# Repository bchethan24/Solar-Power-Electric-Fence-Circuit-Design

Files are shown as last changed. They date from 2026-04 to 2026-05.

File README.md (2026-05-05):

# Solar Powered Electric Fence Circuit

*A high-voltage, renewable energy-based perimeter security system using CD4047 pulse generation and MOSFET power switching.*

---

## Overview

This project features a fully custom-built **Solar Powered Electric Fence**, designed to deliver controlled, safe high-voltage pulses for agricultural and perimeter protection. It integrates a solar charging system with a battery backup to ensure 24/7 off-grid operation without reliance on the power grid.

---

## System Architecture
```
┌────────────────────────────┐       ┌────────────────────────────┐
│   Solar Charging Stage     │       │   Pulse Generation Stage   │
│ • 12V Solar Panel          │       │ • CD4047 Multivibrator     │
│ • LM317L Voltage Regulator │◄─────►│ • Adjustable Frequency     │
│ • 12V 7Ah Battery Storage  │       │ • 46 Hz – 58 Hz Range      │
└────────────────────────────┘       └─────────────┬──────────────┘
                                                   │
                                                   ▼
┌────────────────────────────┐       ┌────────────────────────────┐
│   High-Voltage Stage       │       │      Switching Stage       │
│ • Step-up Transformer      │◄─────►│ • Dual IRF3205 MOSFETs     │
│ • High-Voltage Pulse Out   │       │ • High-Current Handling    │
│ • Safe Deterrent Shocks    │       │ • Low-Loss Power Switching │
└────────────────────────────┘       └────────────────────────────┘
```

## ⚙ Working Principle

1. **Energy Harvesting:** The solar panel generates DC power, which is regulated by the **LM317L** to provide a constant charging voltage to the **12V 7Ah Lead-Acid battery**.
2. **Pulse Timing:** A **CD4047 IC** is configured in astable mode to produce a continuous square wave. The frequency is adjustable (**46–58 Hz**) via a variable resistor to fine-tune the deterrent intensity.
3. **Power Switching:** The logic-level signal from the IC drives the gates of two **IRF3205 MOSFETs**. These MOSFETs switch the battery current through the primary winding of the transformer.
4. **Inductive Boost:** The **Step-up Transformer** converts the low-voltage switched DC into high-voltage, short-duration pulses suitable for long-distance fencing wires.

---

## 🧩 Detailed Hardware Information

### 🧮 Pulse Generation (CD4047)
The timing is governed by the RC network connected to the astable multivibrator pins.

| Component | Value | Function |
| :--- | :--- | :--- |
| **Resistor (R)** | 390 kΩ + 100 kΩ Pot | Frequency Tuning |
| **Capacitor (C)** | 10 nF | Timing Constant |
| **Pulse Period (T)** | 17.16 – 21.56 ms | T = 4.4RC |
| **Frequency (f)** | 46 Hz – 58 Hz | Output Pulse Rate |

### 🔋 Power & Switching
| Component | Specification | Role |
| :--- | :--- | :--- |
| **Voltage Regulator** | LM317L | Battery Charge Control |
| **Storage** | 12V, 7Ah Battery | Lead-Acid Energy Storage |
| **Switching MOSFET** | IRF3205 | High-Current Driver ($V_{DSS}=55V$) |
| **Protection** | Schottky Diodes | Reverse Polarity & Surge Protection |

---

## 📐 Design Features

* **Fully Custom Design:** Optimized schematics and PCB layouts specifically for high-current pulse switching.
* **Off-Grid Optimized:** Designed for outdoor operation with minimal maintenance.
* **Safety Integrated:** Intermittent pulse generation ensures shocks are deterrent but safe for livestock and humans.
* **Modular Layout:** Segmented circuit stages for charging, control, and high-voltage output for easier troubleshooting.

---

## 📂 Repository Contents
- `/hardware`: Schematics, PCB layouts and 3D PCB layout visualizations.
- `/docs`: component datasheets and project report.
- `/manufacturing`: Gerber files of the PCB layouts.

---

## 🧠 Learning Outcomes
- Designing **Battery Charging Circuits** with voltage regulation.
- Implementing **Astable Multivibrators** for precise signal timing.
- Managing **High-Voltage switching** 
- Integrating **Renewable Energy** into practical security applications.

---

## 🧾 License
**MIT License** Permission is granted to use, modify, and distribute under MIT terms.

---

## ✅ Summary
A robust, solar-powered security solution that demonstrates the practical application of **Power Electronics** and **Analog Design**. The system provides a sustainable, cost-effective deterrent for livestock and perimeter management, verified through rigorous testing and custom PCB fabrication.

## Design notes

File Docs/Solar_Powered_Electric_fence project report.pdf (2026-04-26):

P a g e 1 | 18

## Indian Institute of Information Technology Design and Manufacturing, Kurnool

Department of Electronics and Communication Engineering Bachelor of Technology

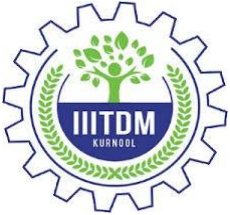
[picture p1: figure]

## Project Report

# Solar Powered Electric Fence

Team members

Praneesh | - 123EC0043
Chethan | - 123EC0049
Abhilash | - 123EC0053
Manideep - 523EC0004
Dinesh - 523EC0007

P a g e 2 | 18

# INDEX

P a g e 3 | 18

### 1. About the Project

### 1.1 Project Aim

The Solar Electric Fence project aims to develop a low-cost, efficient, and renewable energy-powered fencing system. This system is designed to protect agricultural crops and livestock by delivering controlled electric pulses along a fence line. Unlike traditional fencing systems which require mains power or manual management, the solar electric fence harnesses solar energy to operate off-grid, making it ideal for rural and remote locations.

### 1.2 Components and Their Roles

- Solar Panel: Converts sunlight into electrical energy (DC), which powers the entire system and charges the battery.
- Battery (12V 7Ah): Stores electrical energy generated by the solar panel to supply continuous power even during night time or low sunlight.
- LM317L Adjustable Voltage Regulator: Ensures the battery is charged safely with astable and adjustable voltage, protecting it from Voltage fluctuations.
- N-Channel HEXFET Power MOSFETs (IRF3205): Act as electronic switches that drive high-current pulses from the battery into the transformer, enabling efficient pulse generation.
- Transformer: Steps up the low voltage pulses from MOSFETs to high voltage pulses required for energizing the fence wire.
- CD4047 IC: Functions as a pulse generator (astable multi vibrator) to create timing signals that control the switching of the MOSFETs, thereby dictating the pulse repetition rate.

P a g e 4 | 18
- Schottky Diodes: Protect the circuit by preventing reverse current flow, especially during switching and charging phases, owing to their low forward voltage drop and fast switching capability.
- Resistors: Used throughout the circuit for current limiting, voltage division, setting timing parameters, and biasing components.
- Polar and Non-Polar Capacitors: Used for filtering power ripple, timing in multi vibrator circuits, energy storage, and reducing electrical noise.
- LED Indicators: Provide visual feedback on power status, charging state, and pulse generation, facilitating easy monitoring.
- Switches: Allow manual control to enable or disable charging and fence energization.

### 2. Project Schematics

### 2.1 Overview

The schematic is divided into three major sections:

- Power Supply and Charging Circuit: Includes the solar panel input, diode protection, LM317L voltage regulator, charging control switches, and battery storage.
- Pulse Generation Circuit: Built around the CD4047 astable multi vibrator IC which generates a square wave to control the gate of MOSFETs.
- Pulse Amplification and Transformer Section: MOSFETs switch the battery power through the transformer primary, stepping voltage up to deliver sharp pulses on the fence wire.

BOARD 1

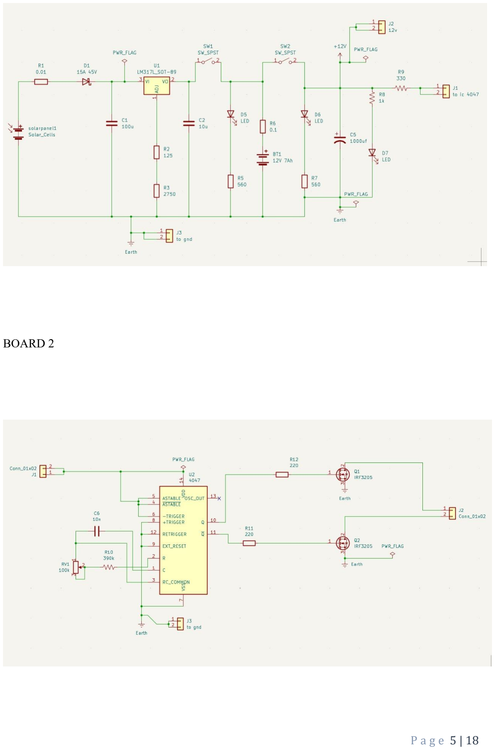
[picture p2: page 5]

P a g e 5 | 18

BOARD 2

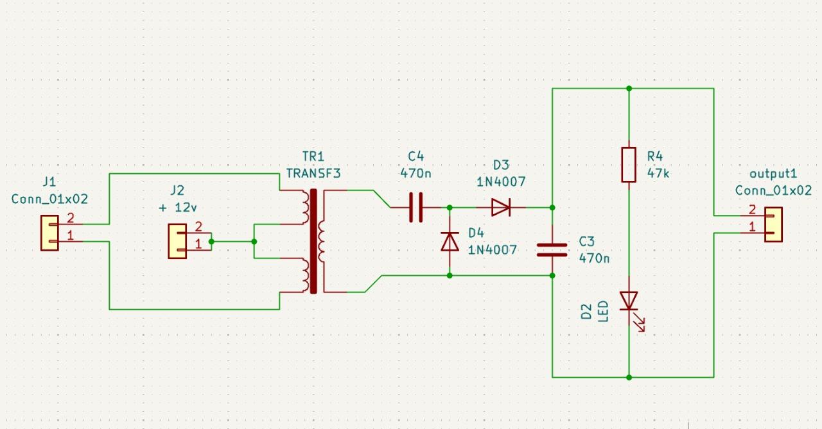
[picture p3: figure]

P a g e 6 | 18

BOARD 3

Figure : Schematic diagram of the Solar power Electric Fence

The schematic of the solar-powered electric fence circuit integrates all the essential power generation and pulse delivery stages, as summarized below:

- The solar panel interfaces with the battery charging circuit through diodes and capacitors to store energy, while switches and fuses regulate power input for safe operation.
- The 555 timer ICs provide pulse generation and triggering signals to drive the MOSFETs and transformer, enabling high-voltage output for fence energization.
- An ignition coil and transformer are used to step up the voltage from the 12V battery to deliver high-voltage pulses, ensuring effective deterrence along the fence wire.
- Supporting components such as resistors, capacitors, and LEDs are utilized for timing, filtering, status indication, and protection against electrical surges and faults.

P a g e 7 | 18

### 3. Working Principle

The core functioning of the solar electric fence depends on generating high-voltage electric pulses at regulated intervals:

1. The solar panel converts sunlight into DC electricity, charging the 12V battery through an LM317L voltage regulator to avoid overcharging.
2. The CD4047 IC is configured as an astable multi vibrator producing a continuous square wave used to switch MOSFETs alternately.
3. Each MOSFET switches the battery voltage through a center - tapped transformer primary winding, causing the transformer secondary to produce high-voltage pulses.
4. These pulses are transmitted along the fence wires. When an animal contacts the fence, the circuit completes briefly, delivering a safe but discomforting shock, thereby deterring intrusion.
5. LEDs and other indicators provide the user with system status, including battery charge and output pulse activity.

Pulse Timing Calculation

The pulse frequency, f, generated by the CD4047 in astable mode can be approximated by

where R and C are the timing resistor and capacitor connected externally to the IC. Adjusting these values changes the pulse repetition rate.

P a g e 8 | 18

### 4. Design Considerations

### 4.1 Electrical Considerations

Careful voltage and current regulation protects battery longevity. Efficient MOSFETs minimize power loss during switching. Use of Schottky diodes reduces voltage drop and improves circuit response times.

### 4.2 Layout and Wiring

Short, thick wires and neat PCB layout reduce resistance and interference. Proper placement of decoupling capacitors near active devices ensures stability.

### 4.3 Mechanical and Environmental

Components and wiring should be weatherproofed for outdoor use. Adequate spacing and mounting support thermal dissipation and protect parts against mechanical stress.

### 4.4 Thermal Management

High-current MOSFETs and voltage regulators should have heatsinks. Sufficient airflow and isolation prevent overheating and increase reliability.

### 5. Layout

The PCB layout has been designed for compactness, signal integrity, and ease of assembly. The layout optimizes routing of power and signal lines, placing critical components like the voltage regulator and MOSFETs to minimize noise and thermal hotspots.

BOARD 1

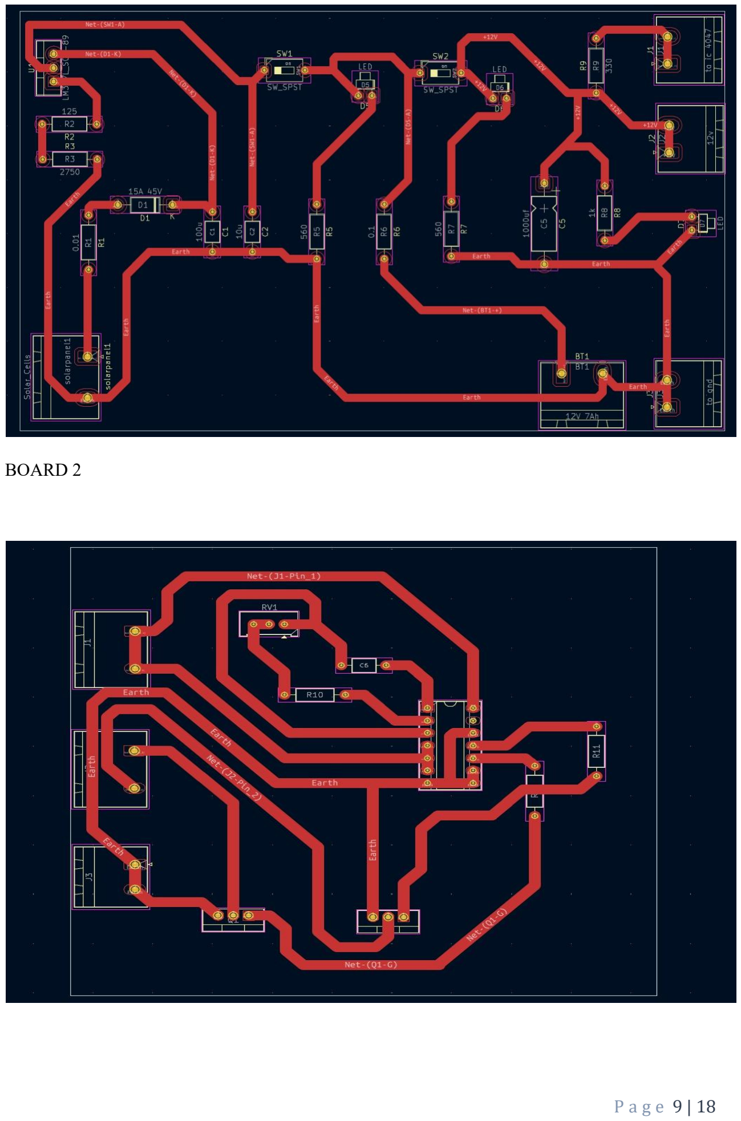
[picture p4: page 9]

P a g e 9 | 18

BOARD 2

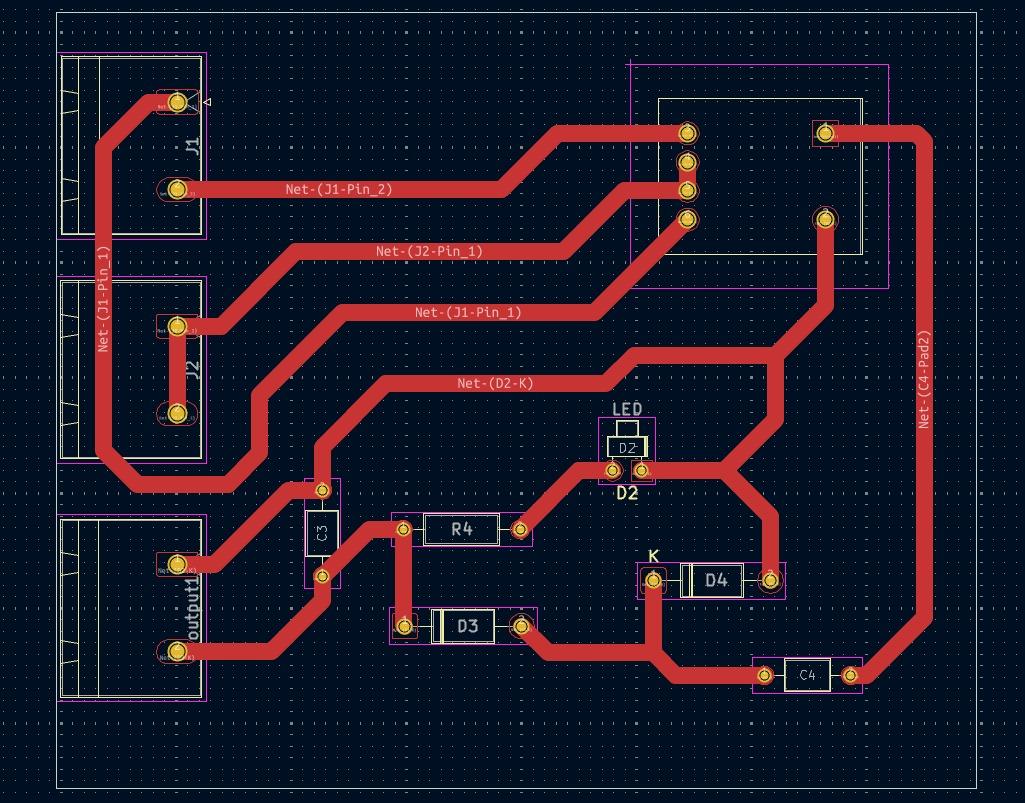
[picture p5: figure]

P a g e 10 | 18

BOARD 3

Figure 2: PCB layout

### 6. Front Copper

The front copper layer contains the main routing for power lines, signal traces, and pads for through-hole and surface mount components. Care was taken to ensure wide tracks for high current paths.

BOARD 1

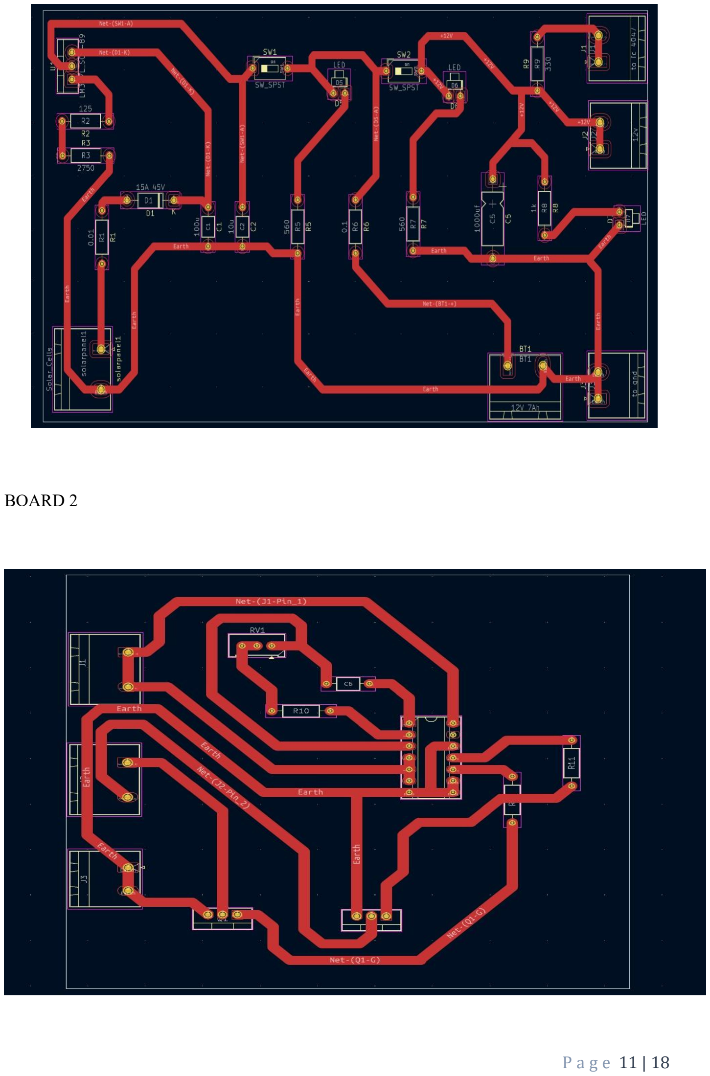
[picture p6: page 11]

P a g e 11 | 18

BOARD 2

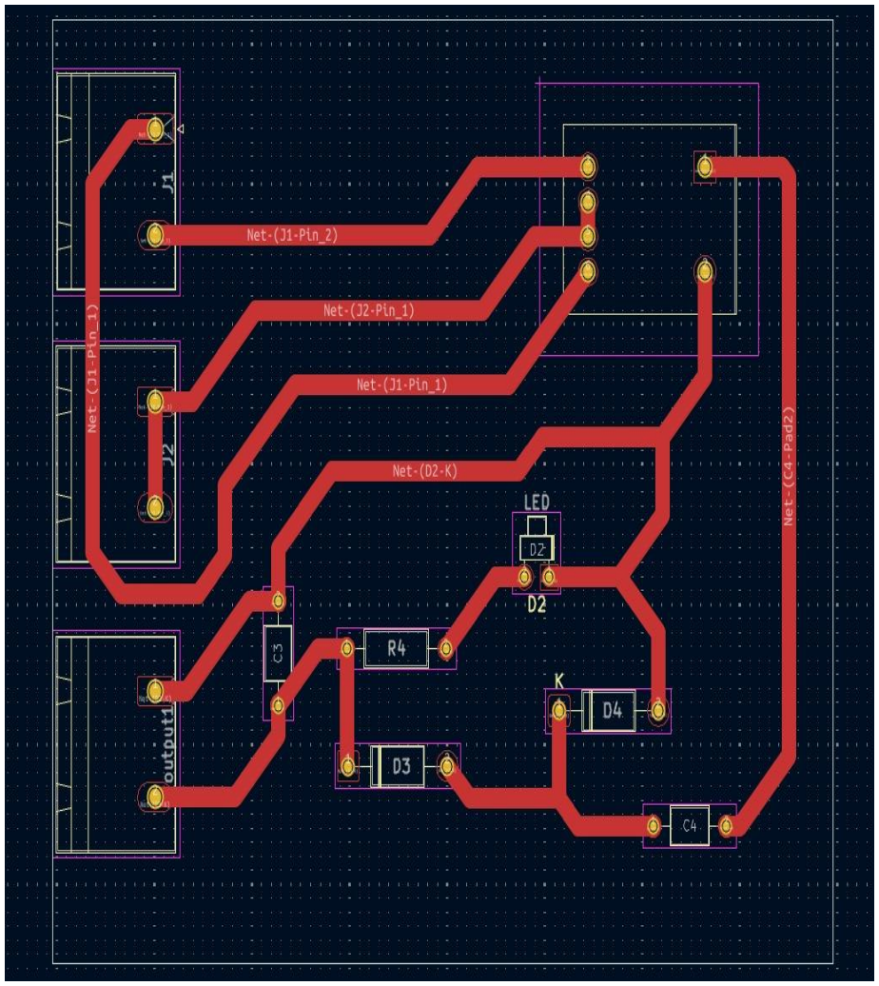
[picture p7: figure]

P a g e 12 | 18

BOARD 3

Figure: Front copper layer of the PCB.

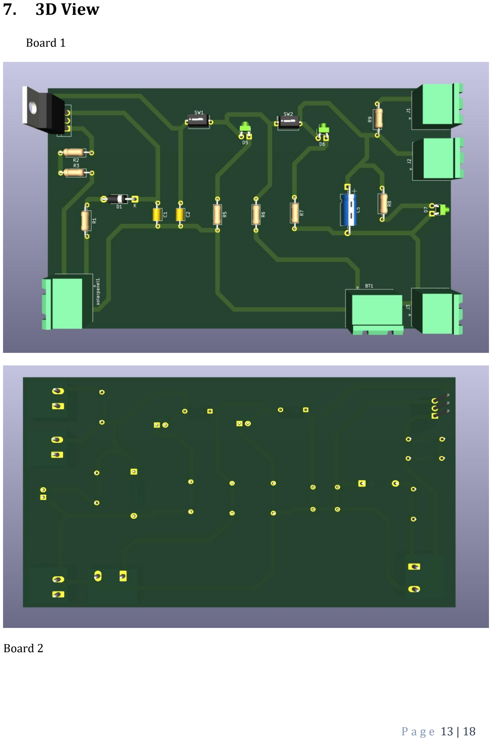
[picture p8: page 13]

P a g e 13 | 18

### 7. 3D View

Board 1

Board 2

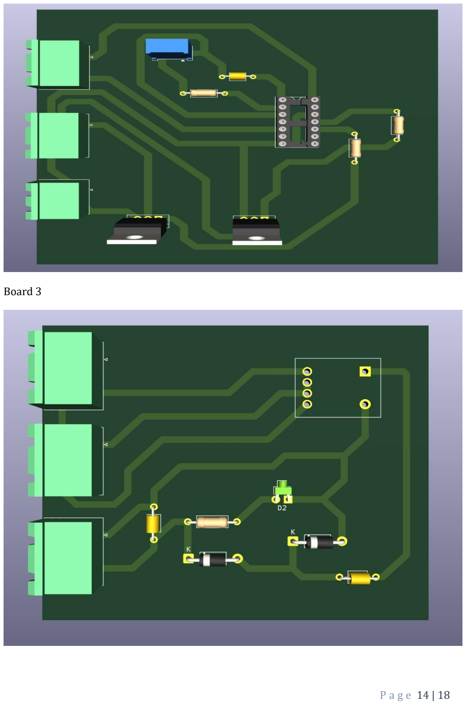
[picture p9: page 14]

P a g e 14 | 18

Board 3

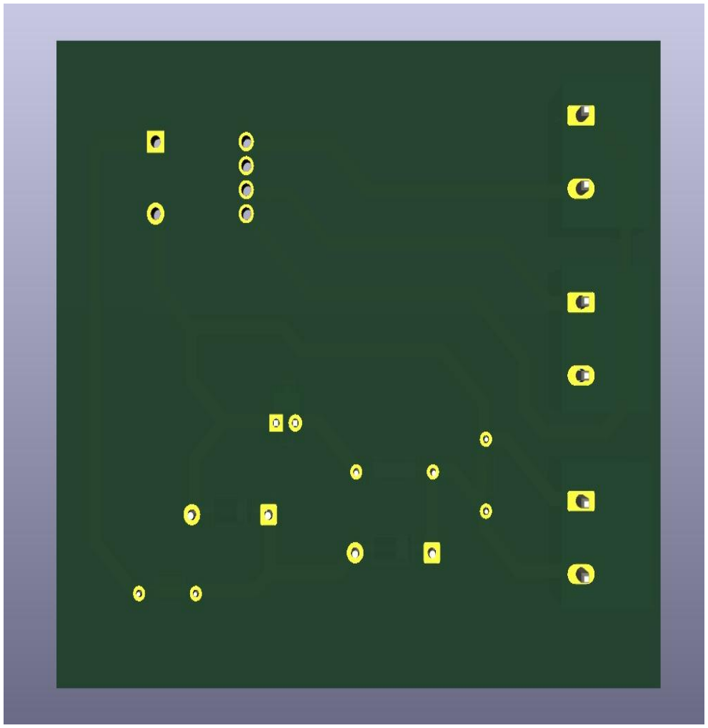
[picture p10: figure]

P a g e 15 | 18

### 8. Legends

The silkscreen legends provide the component designators, polarity indicators, and assembly guides for accurate component placement and troubleshooting.

BOARD 1

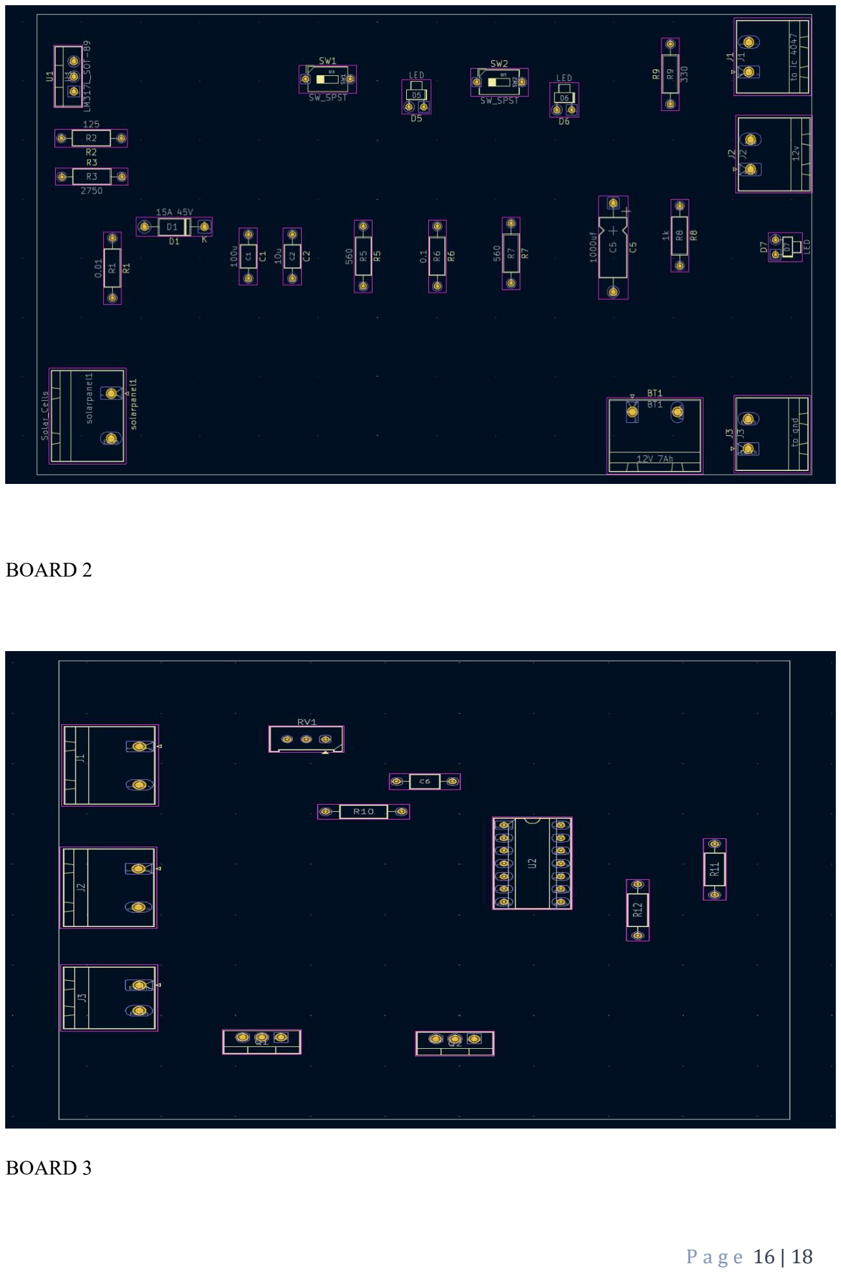
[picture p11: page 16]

P a g e 16 | 18

BOARD 2

BOARD 3

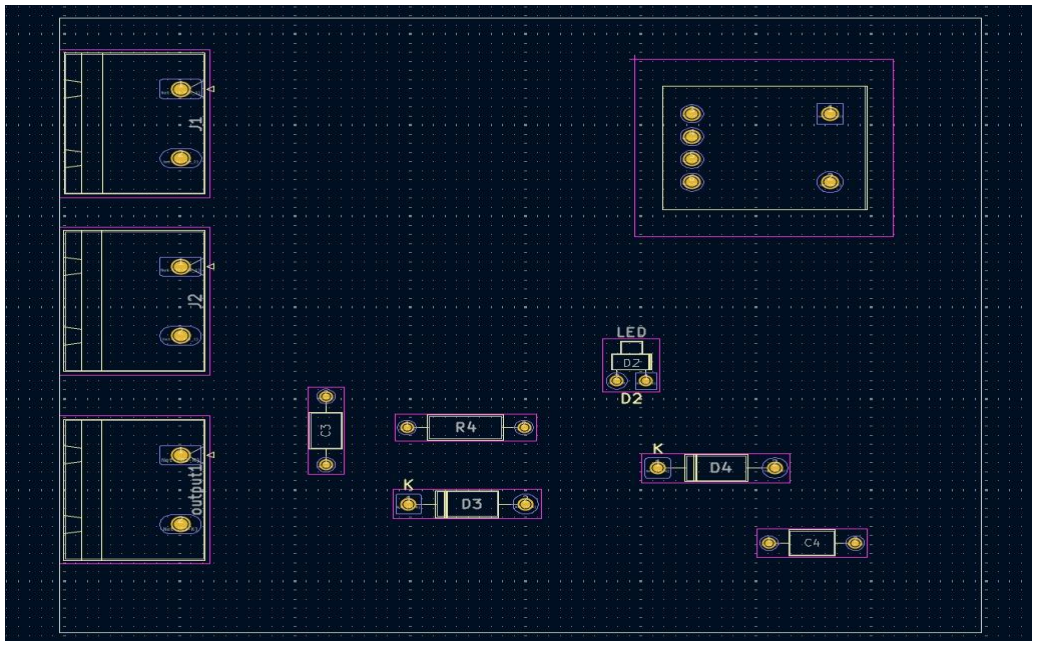
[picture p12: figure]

P a g e 17 | 18

Figures: Silkscreen Legend Layer of PCB

### 9. Overall Project Summary

The Solar Powered Electric Fence project demonstrates a sustainable and cost-effective solution for protecting agricultural fields and livestock using renewable energy. The system utilizes solar energy to power a fence that delivers controlled electric pulses, effectively deterring animals and intruders without causing harm.

The design integrates key electronic components such as the solar panel, LM317L voltage regulator, CD4047 IC, MOSFETs, transformer, and protective diodes to ensure reliable performance. The solar panel charges a 12V battery, enabling continuous operation even during night time or cloudy conditions. The CD4047 IC generates pulses that switch the MOSFETs, which in turn drive the transformer to produce high-voltage pulses transmitted along the fence wire.

P a g e 18 | 18

This project emphasizes energy efficiency, safety, and practicality. By operating completely off-grid, it offers a dependable fencing solution for remote and rural areas. The system’s PCB layout, thermal management, and protective design ensure durability and ease of maintenance in outdoor environments.

Overall, the project successfully integrates renewable energy, electronics, and safety engineering principles to create an effective solar-powered electric fencing system. It serves as a valuable step toward sustainable agricultural protection and energy-efficient rural technology.

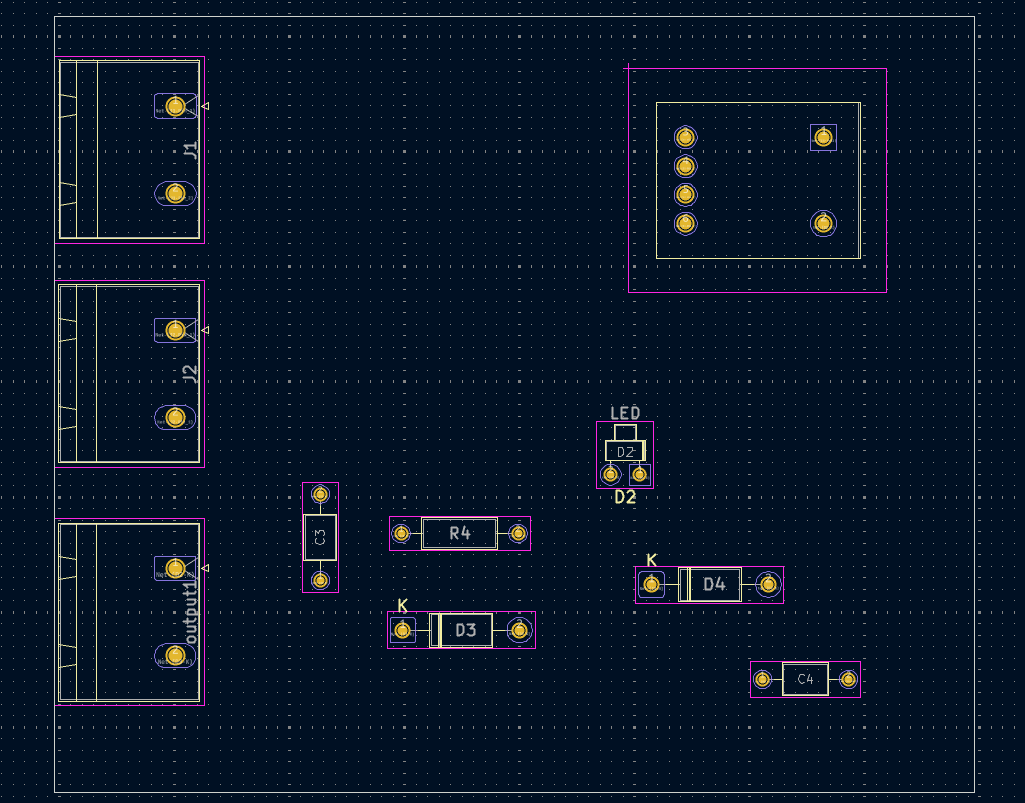
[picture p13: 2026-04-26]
Hardware/Main_Control_Board/Assets/third_part/legend.png

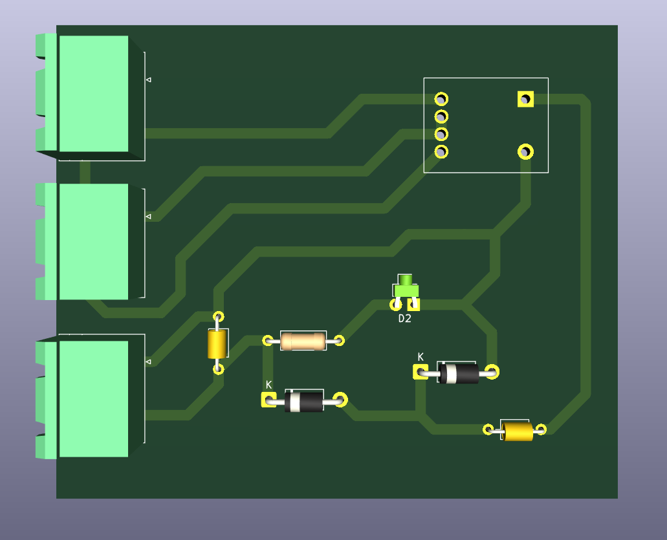
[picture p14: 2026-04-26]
Hardware/Main_Control_Board/Assets/third_part/3d front view.png

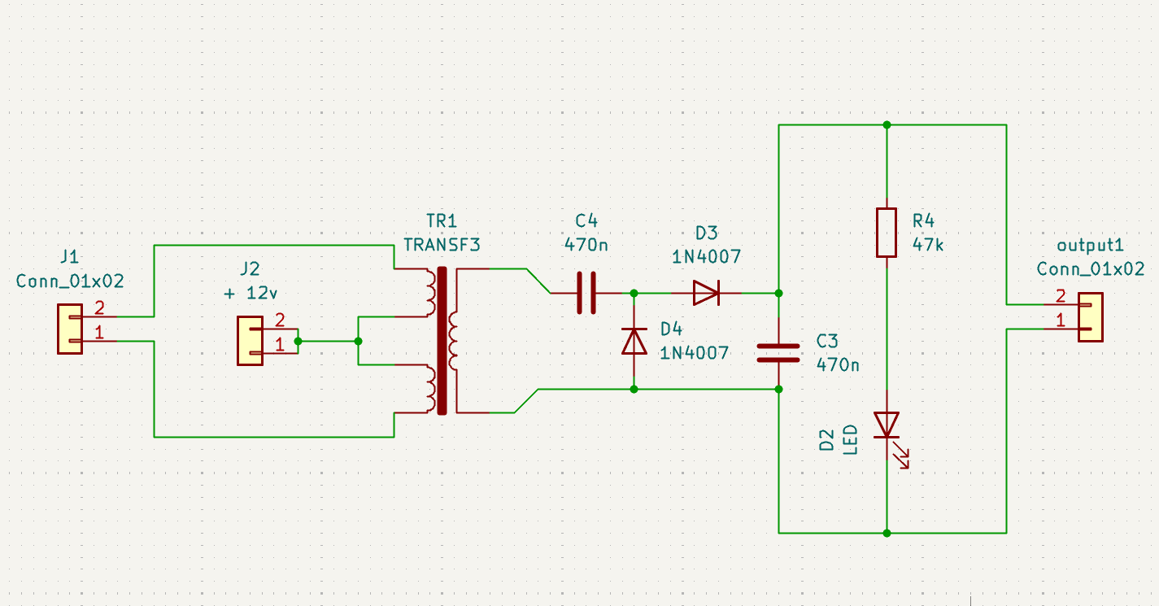
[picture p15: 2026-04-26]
Hardware/Main_Control_Board/Assets/third_part/schematic.png

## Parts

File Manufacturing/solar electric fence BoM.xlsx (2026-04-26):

SL.NO | ITEM | DESCRIPTION | VALUE | MAKE | PRICE | LINK
1 | LM317 | Linear Voltage Regulator IC Positive Adjustable 1 Output 1.5A TO-220 | 1 Output 1.5A TO-220 | Lumimax Optoelectronic Technology | $0.53 | https://www.digikey.in/en/products/detail/lumimax-optoelectronic-technology/LM317/24373406
2 | MPSA06 | Bipolar (BJT) Transistor NPN 80 V 500 mA 100MHz 625 mW Through Hole TO-92-3 | TRANS NPN 80V 0.5A TO-92-3 | onsemi | $0.44 | https://www.digikey.in/en/products/detail/onsemi/MPSA06/148257
3 | BAT54WS-7-F | Diode 30 V 100mA Surface Mount SOD-323 | DIODE SCHOTTKY 30V 100MA SOD323 | Diodes Incorporated | $0.10 | https://www.digikey.in/en/products/detail/diodes-incorporated/BAT54WS-7-F/804865
4 | 1N4007 | Diode 1000 V 1A Through Hole DO-204AC (DO-41) | DIODE STANDARD 1000V 1A DO204AC | Diotec Semiconductor | $0.10 | https://www.digikey.in/en/products/detail/diotec-semiconductor/1N4007/18833652
5 | LTL-4233 | Green 569nm LED Indication - Discrete 2.1V Radial | LED GREEN DIFFUSED T-1 3/4 T/H | Lite-On Inc. | $0.19 | https://www.digikey.in/en/products/detail/liteon/LTL-4233/217580
6 | 3FD-212 | PWR XFMR LAMINATED 1.1VA TH | Parallel 180mA, Series 90mA;secondary Parallel 6.3V, Series 12.6V;primary 115V, 230V | Tamura | $4.97 | https://www.digikey.in/en/products/detail/tamura/3FD-212/98294
7 | MR5FT10L0 | 10 mOhms ±1% 5W Through Hole Resistor Axial Current Sense, Moisture Resistant, Non-Inductive, Non-Magnetic Metal Foil | RES 0.01 OHM 1% 5W AXIAL | Stackpole Electronics Inc | $1.83 | MR5FT10L0 Stackpole Electronics Inc | Resistors | DigiKey (https://www.digikey.in/en/products/detail/stackpole-electronics-inc/MR5FT10L0/1650262)
8 | WHER10FET | 100 mOhms ±1% 5W Through Hole Resistor Axial Wirewound | RES 0.1 OHM 1% 5W AXIAL | Ohmite | $1.63 | WHER10FET Ohmite | Resistors | DigiKey (https://www.digikey.in/en/products/detail/ohmite/WHER10FET/3114531)
9 | RN60D1250FB14 | 125 Ohms ±1% 0.25W, 1/4W Through Hole Resistor Axial Flame Retardant Coating, Military, Moisture Resistant, Safety Metal Film | RES 125 OHM 1% 1/4W AXIAL | Vishay Dale | $0.47 | RN60D1250FB14 Vishay Dale | Resistors | DigiKey (https://www.digikey.in/en/products/detail/vishay-dale/RN60D1250FB14/3357714)
10 | CF14JT220R | 220 Ohms ±5% 0.25W, 1/4W Through Hole Resistor Axial Carbon Film | RES 220 OHM 5% 1/4W AXIAL | Stackpole Electronics Inc | $0.10 | CF14JT220R Stackpole Electronics Inc | Resistors | DigiKey (https://www.digikey.in/en/products/detail/stackpole-electronics-inc/CF14JT220R/1741346)
11 | CF12JT750R | 750 Ohms ±5% 0.5W, 1/2W Through Hole Resistor Axial Carbon Film | RES 750 OHM 5% 1/2W AXIAL | Stackpole Electronics Inc | $0.10 | CF12JT750R Stackpole Electronics Inc | Resistors | DigiKey (https://www.digikey.in/en/products/detail/stackpole-electronics-inc/CF12JT750R/1741205)
12 | CF14JT10K0 | 10 kOhms ±5% 0.25W, 1/4W Through Hole Resistor Axial Carbon Film | RES 10K OHM 5% 1/4W AXIAL | Stackpole Electronics Inc | $0.10 | CF14JT10K0 Stackpole Electronics Inc | Resistors | DigiKey (https://www.digikey.in/en/products/detail/stackpole-electronics-inc/CF14JT10K0/1741265)
13 | C1047KJL | 47 kOhms ±5% 10W Through Hole Resistor Axial Wirewound | RES 47K OHM 5% 10W AXIAL | TE Connectivity Passive Product | $6.96 | C1047KJL TE Connectivity Passive Product | Resistors | DigiKey (https://www.digikey.in/en/products/detail/te-connectivity-passive-product/C1047KJL/5399914)
14 | 672D108F012DS3J | 1000 µF 12 V Aluminum Electrolytic Capacitors Radial, Can 150mOhm @ 120Hz | CAP ALUM 1000UF 12V RADIAL TH | Vishay Sprague | $4.83 | https://www.digikey.in/en/products/detail/vishay-sprague/672D108F012DS3J/5611973
15 | 865080343009 | 100 µF 16 V Aluminum Electrolytic Capacitors Radial, Can - SMD 2000 Hrs @ 105°C | CAP ALUM 100UF 20% 16V SMD | Würth Elektronik | $0.28 | https://www.digikey.in/en/products/detail/w%C3%BCrth-elektronik/865080343009/5728014
16 | 865080340001 | 10 µF 16 V Aluminum Electrolytic Capacitors Radial, Can - SMD 2000 Hrs @ 105°C | CAP ALUM 10UF 20% 16V SMD | Würth Elektronik | $0.18 | https://www.digikey.in/en/products/detail/w%C3%BCrth-elektronik/865080340001/5728006
17 | CL10B473KO8NNNC | 0.047 µF ±10% 16V Ceramic Capacitor X7R 0603 (1608 Metric) | CAP CER 0.047UF 16V X7R 0603 | Samsung Electro-Mechanics | $0.10 | https://www.digikey.in/en/products/detail/samsung-electro-mechanics/CL10B473KO8NNNC/3887737
18 | 860010672004 | 0.47 µF 50 V Aluminum Electrolytic Capacitors Radial, Can 2000 Hrs @ 85°C | CAP ALUM 0.47UF 20% 50V RADIAL | Würth Elektronik | $0.11 | https://www.digikey.in/en/products/detail/w%C3%BCrth-elektronik/860010672004/5726903
19 | C5750X7T2J474K250KC | 0.47 µF ±10% 630V Ceramic Capacitor X7T 2220 (5750 Metric) | CAP CER 0.47UF 630V X7T 2220 | TDK Corporation | $5.66 | https://www.digikey.in/en/products/detail/tdk-corporation/C5750X7T2J474K250KC/2733214
20
21
22
23 | STPS1545 | Schottky Diode 45 V 15A Through Hole TO-220FPAC | DIODE SCHOTTKY 45V 15A TO220FPAC | STMicroelectronics | $1.09 | https://www.digikey.in/en/products/detail/stmicroelectronics/STPS1545FP/2170952
 | IRF3205 | SME IRF3205 MOSFET | Model Name :IRF3205 Continuous drain current(A): 110 Drain to Source Voltage (V)55 Gate Threshold Voltage (V) 2 | Generic | $1.09 | https://robu.in/product/sme-irf3205-mosfet/#tab-product_download_66939_tab
 | HM4304-ND | Laminated Core 2.4VA Power Transformer 115V Primary Parallel 18V, Series 36V Secondary Parallel 130mA, Series 65mA Through Hole | PWR XFMR LAMINATED 2.4VA TH | Hammond Manufacturing | $9.89 | https://www.digikey.in/en/products/detail/hammond-manufacturing/164E36/455638?gclsrc=aw.ds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

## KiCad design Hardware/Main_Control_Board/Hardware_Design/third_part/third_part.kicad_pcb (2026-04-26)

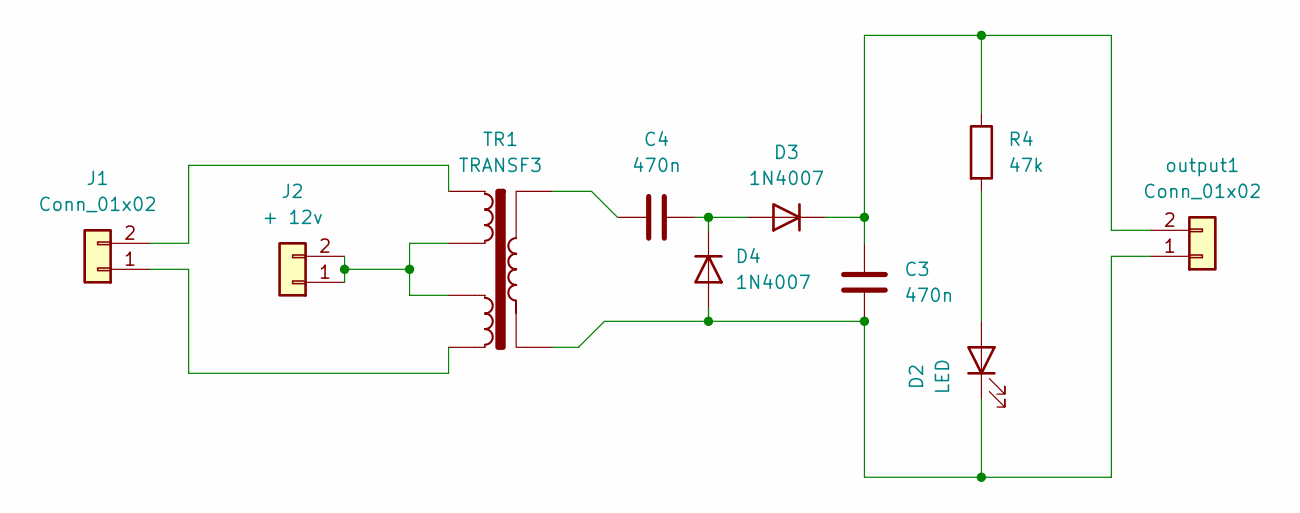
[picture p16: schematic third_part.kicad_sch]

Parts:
C3, C4: 470n; C_Axial_L3.8mm_D2.6mm_P7.50mm_Horizontal
D2: LED; LED_D1.8mm_W1.8mm_H2.4mm_Horizontal_O1.27mm_Z1.6mm
D3, D4: 1N4007; D_DO-41_SOD81_P10.16mm_Horizontal
J1: Conn_01x02; PhoenixContact_GMSTBA_2,5_2-G-7,62_1x02_P7.62mm_Horizontal
J2: + 12v; PhoenixContact_GMSTBA_2,5_2-G-7,62_1x02_P7.62mm_Horizontal
R4: 47k; R_Axial_DIN0207_L6.3mm_D2.5mm_P10.16mm_Horizontal
TR1: TRANSF3; Transformer_Myrra_EI30-5_44000_Horizontal ( self made )
output1: Conn_01x02; PhoenixContact_GMSTBA_2,5_2-G-7,62_1x02_P7.62mm_Horizontal

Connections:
unnamed: C4.2, TR1.1
unnamed: D2.2 (A), R4.2
unnamed: C3.2, D2.1 (K), D4.2 (A), TR1.2, output1.1
unnamed: C4.1, D3.2 (A), D4.1 (K)
unnamed: C3.1, D3.1 (K), R4.1, output1.2
unnamed: J1.1, TR1.6
unnamed: J1.2, TR1.3
unnamed: J2.1, J2.2, TR1.4, TR1.5

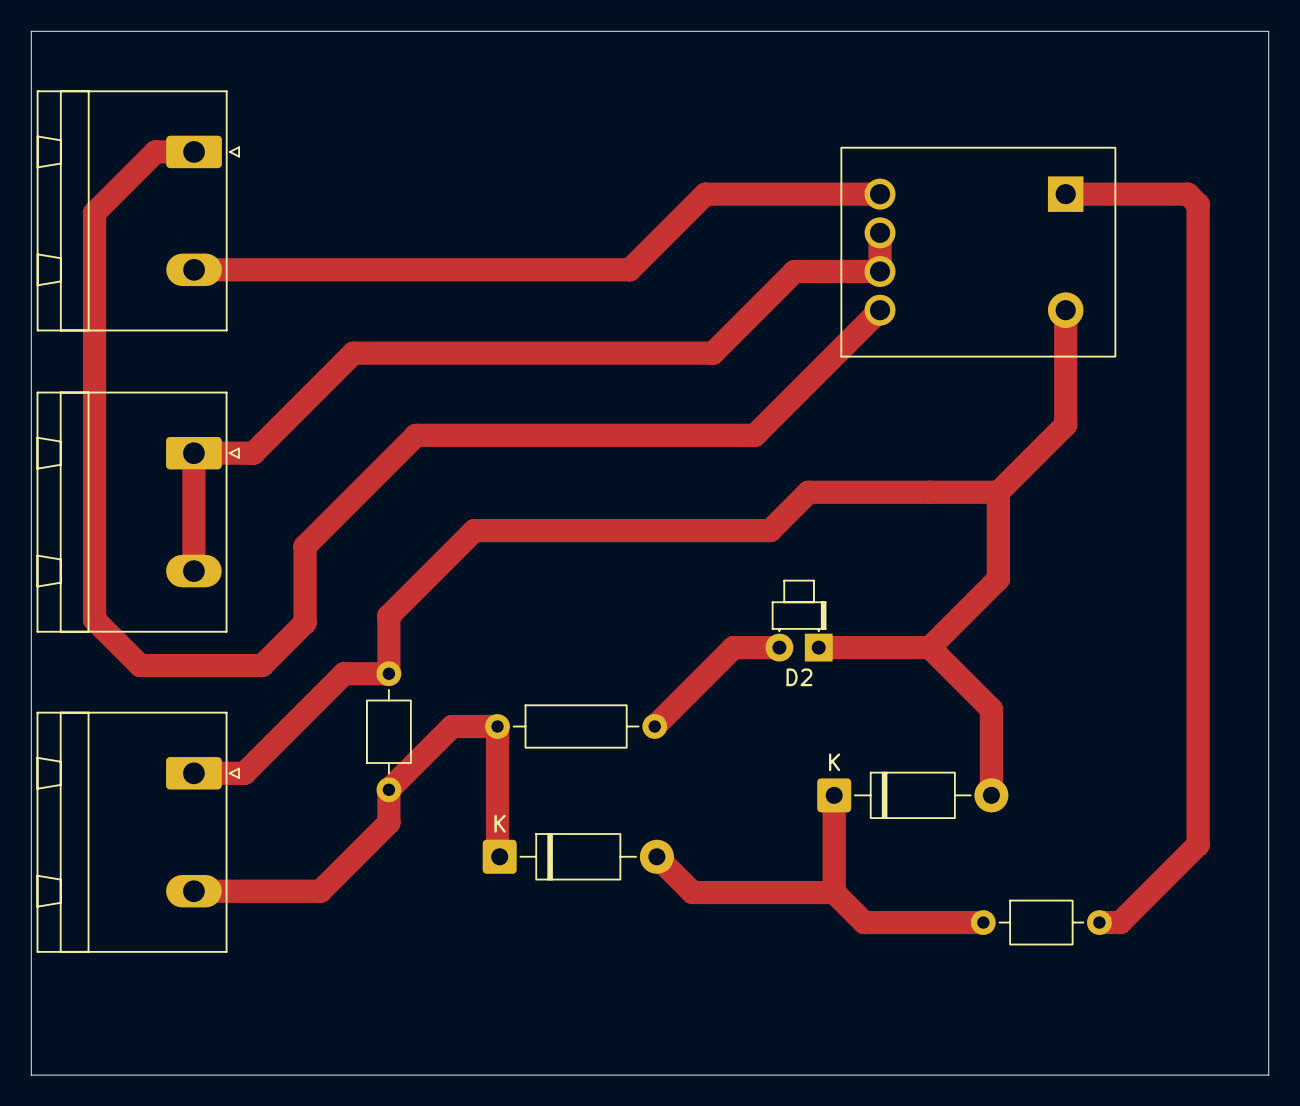
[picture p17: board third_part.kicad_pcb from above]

Board: 2 copper layers, 80.0 x 67.5 mm, 10 parts (0 on the bottom side), 8 nets.

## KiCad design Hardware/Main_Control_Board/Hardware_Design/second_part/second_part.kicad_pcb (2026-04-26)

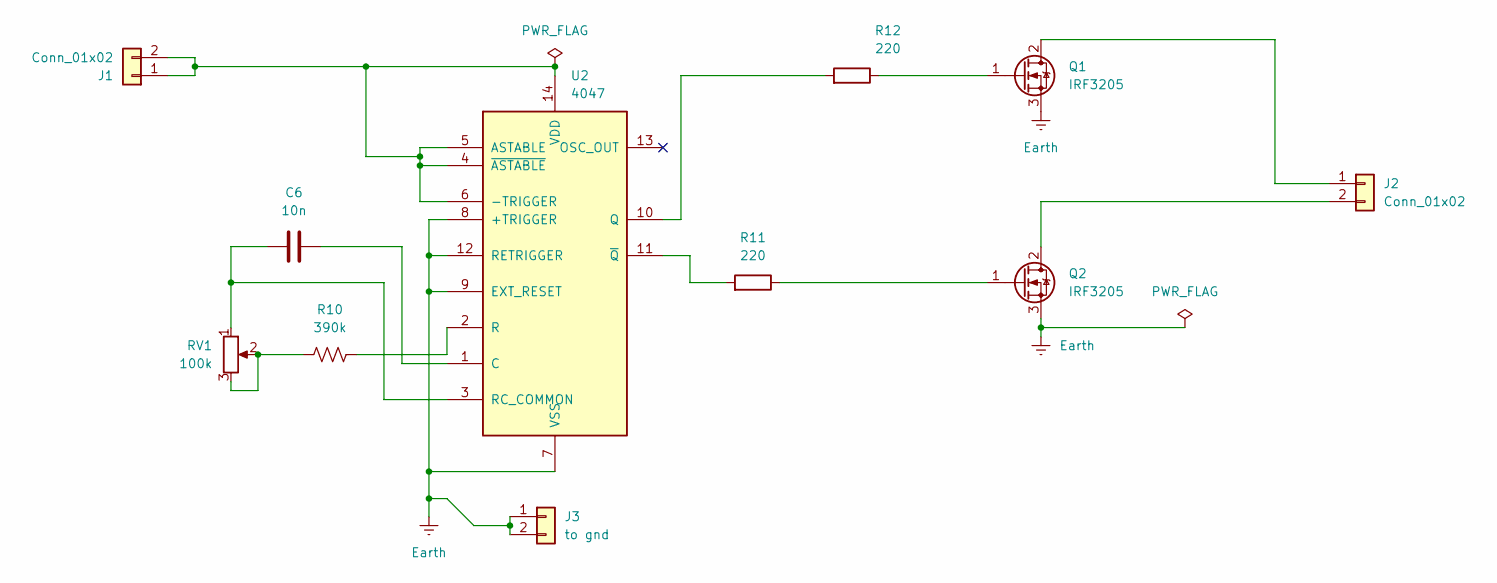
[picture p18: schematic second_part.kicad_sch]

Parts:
C6: 10n; C_Axial_L3.8mm_D2.6mm_P7.50mm_Horizontal
J1, J2: Conn_01x02; PhoenixContact_GMSTBA_2,5_2-G-7,62_1x02_P7.62mm_Horizontal
J3: to gnd; PhoenixContact_MSTBA_2,5_2-G-5,08_1x02_P5.08mm_Horizontal
Q1, Q2: IRF3205; TO-220-3_Vertical
R10: 390k; R_Axial_DIN0207_L6.3mm_D2.5mm_P10.16mm_Horizontal
R11, R12: 220; R_Axial_DIN0207_L6.3mm_D2.5mm_P10.16mm_Horizontal
RV1: 100k; Potentiometer_Bourns_3386W_Horizontal
U2: 4047; DIP-14_W7.62mm_Socket_LongPads

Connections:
Earth: J3.1, J3.2, Q1.3 (S), Q2.3 (S), U2.7 (VSS), U2.8 (+TRIGGER), U2.9 (EXT_RESET), U2.12 (RETRIGGER)
unnamed: J1.1, J1.2, U2.4 (~ASTABLE), U2.5 (ASTABLE), U2.6 (-TRIGGER), U2.14 (VDD)
unnamed: J2.1, Q1.2 (D)
unnamed: J2.2, Q2.2 (D)
unnamed: Q1.1 (G), R12.1
unnamed: Q2.1 (G), R11.1
unnamed: R10.1, RV1.2, RV1.3
unnamed: C6.2, U2.1 (C)
unnamed: R12.2, U2.10 (Q)
unnamed: R10.2, U2.2 (R)
unnamed: C6.1, RV1.1, U2.3 (RC_COMMON)
unnamed: R11.2, U2.11 (~Q)

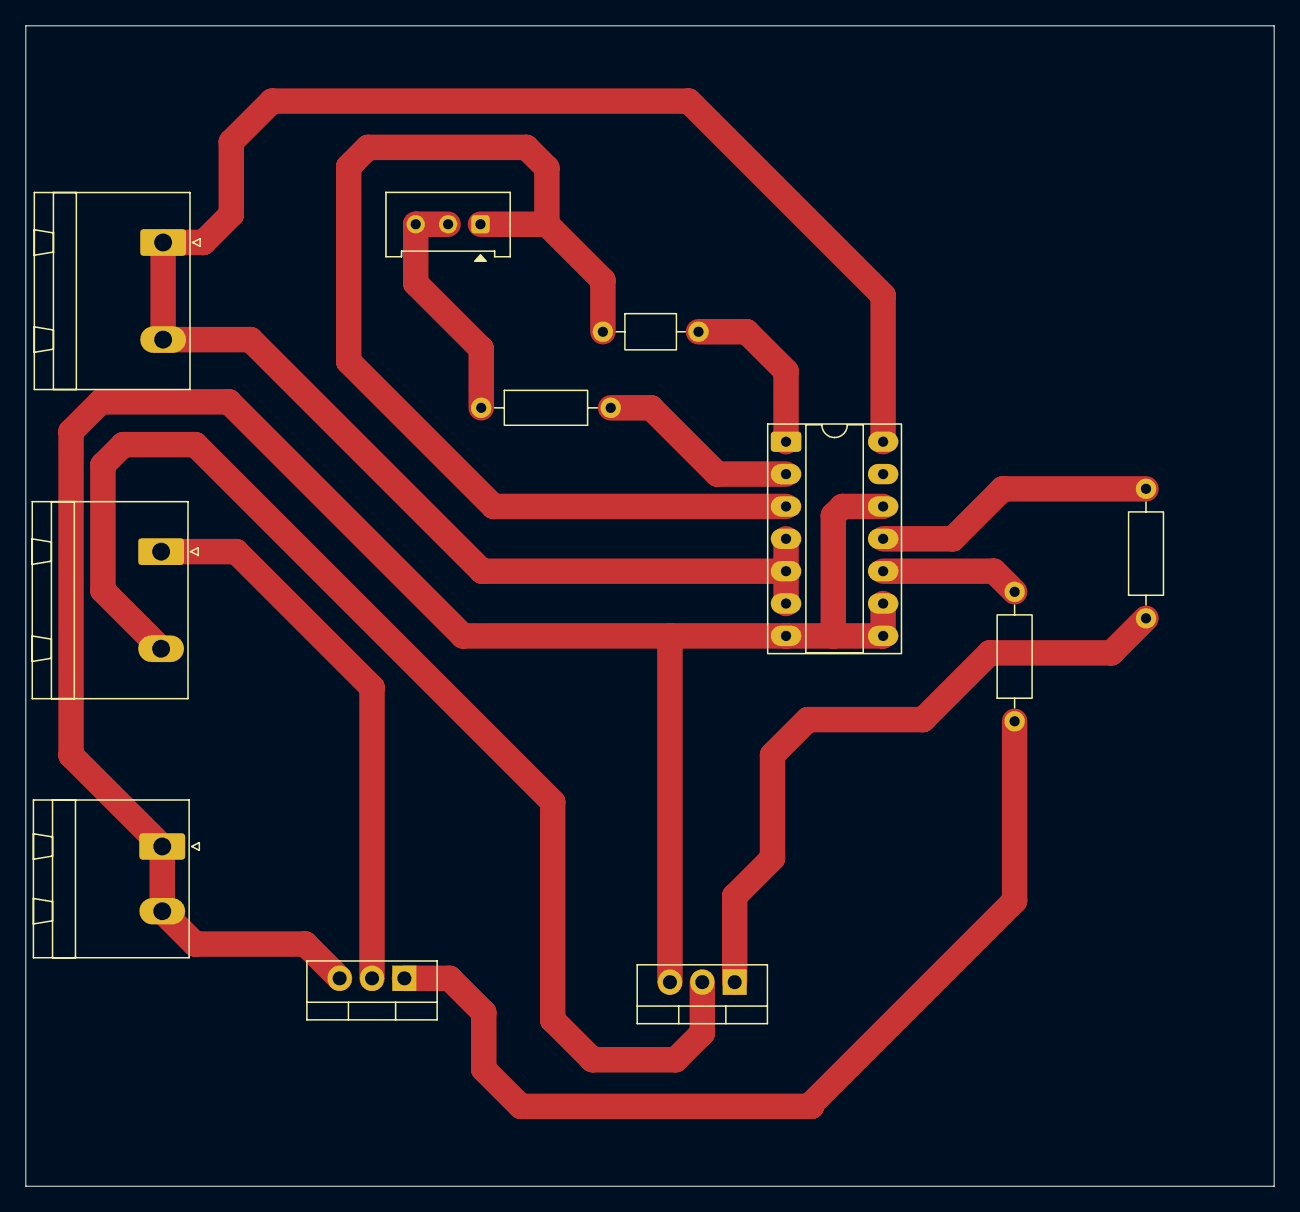
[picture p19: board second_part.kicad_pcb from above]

Board: 2 copper layers, 98.0 x 91.1 mm, 11 parts (0 on the bottom side), 12 nets.

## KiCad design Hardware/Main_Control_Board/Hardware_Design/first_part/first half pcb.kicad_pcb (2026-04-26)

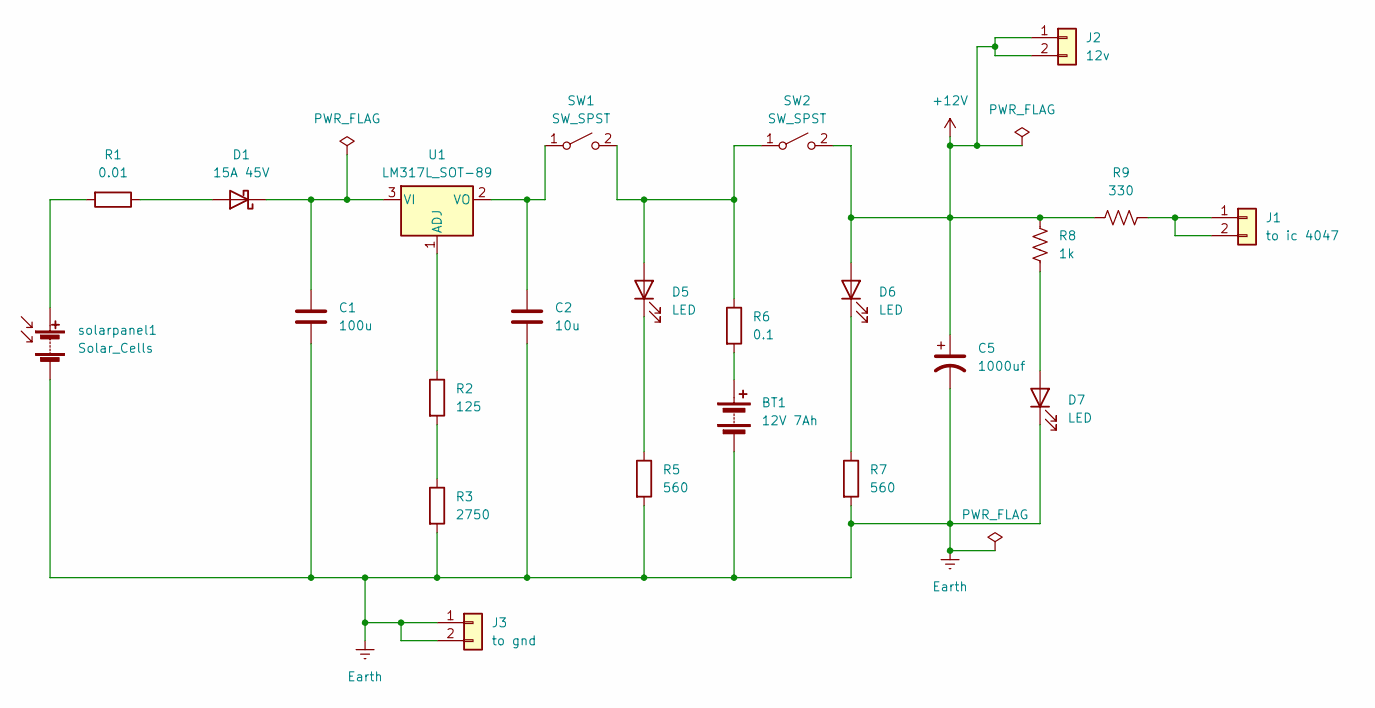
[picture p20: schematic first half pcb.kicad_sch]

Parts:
BT1: 12V 7Ah; PhoenixContact_GMSTBA_2,5_2-G-7,62_1x02_P7.62mm_Horizontal
C1: 100u; C_Axial_L3.8mm_D2.6mm_P7.50mm_Horizontal
C2: 10u; C_Axial_L3.8mm_D2.6mm_P7.50mm_Horizontal
C5: 1000uf; CP_Axial_L10.0mm_D4.5mm_P15.00mm_Horizontal
D1: 15A 45V; D_DO-41_SOD81_P10.16mm_Horizontal
D5, D6, D7: LED; LED_D1.8mm_W1.8mm_H2.4mm_Horizontal_O1.27mm_Z1.6mm
J1: to ic 4047; PhoenixContact_MSTBA_2,5_2-G-5,08_1x02_P5.08mm_Horizontal
J2: 12v; PhoenixContact_MSTBA_2,5_2-G-5,08_1x02_P5.08mm_Horizontal
J3: to gnd; PhoenixContact_MSTBA_2,5_2-G-5,08_1x02_P5.08mm_Horizontal
R1: 0.01; R_Axial_DIN0207_L6.3mm_D2.5mm_P10.16mm_Horizontal
R2: 125; R_Axial_DIN0207_L6.3mm_D2.5mm_P10.16mm_Horizontal
R3: 2750; R_Axial_DIN0207_L6.3mm_D2.5mm_P10.16mm_Horizontal
R5, R7: 560; R_Axial_DIN0207_L6.3mm_D2.5mm_P10.16mm_Horizontal
R6: 0.1; R_Axial_DIN0207_L6.3mm_D2.5mm_P10.16mm_Horizontal
R8: 1k; R_Axial_DIN0207_L6.3mm_D2.5mm_P10.16mm_Horizontal
R9: 330; R_Axial_DIN0207_L6.3mm_D2.5mm_P10.16mm_Horizontal
SW1, SW2: SW_SPST; SW_DIP_SPSTx01_Slide_6.7x4.1mm_W7.62mm_P2.54mm_LowProfile
U1: LM317L_SOT-89; TO-220-3_Vertical
solarpanel1: Solar_Cells; PhoenixContact_GMSTBA_2,5_2-G-7,62_1x02_P7.62mm_Horizontal

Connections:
+12V: C5.1, D6.2 (A), J2.1, J2.2, R8.1, R9.1, SW2.2 (B)
Earth: BT1.2 (-), C1.2, C2.2, C5.2, D7.1 (K), J3.1, J3.2, R3.2, R5.2, R7.2, solarpanel1.2 (-)
unnamed: BT1.1 (+), R6.2
unnamed: D1.2 (A), R1.1
unnamed: C1.1, D1.1 (K), U1.3 (VI)
unnamed: D5.2 (A), R6.1, SW1.2 (B), SW2.1 (A)
unnamed: D5.1 (K), R5.1
unnamed: D6.1 (K), R7.1
unnamed: D7.2 (A), R8.2
unnamed: J1.1, J1.2, R9.2
unnamed: R2.2, R3.1
unnamed: C2.1, SW1.1 (A), U1.2 (VO)
unnamed: R2.1, U1.1 (ADJ)
unnamed: R1.2, solarpanel1.1 (+)

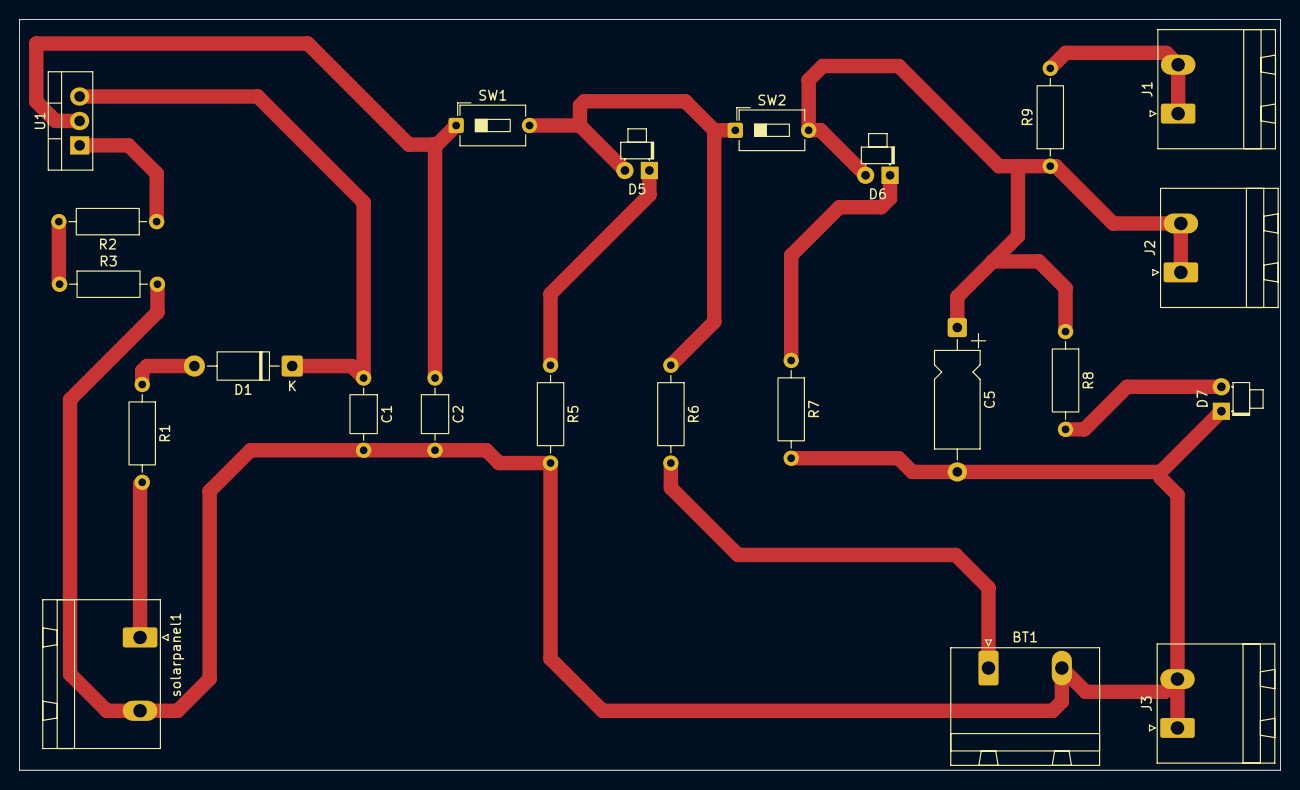
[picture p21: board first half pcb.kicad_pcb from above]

Board: 2 copper layers, 131.0 x 78.0 mm, 23 parts (0 on the bottom side), 14 nets.
